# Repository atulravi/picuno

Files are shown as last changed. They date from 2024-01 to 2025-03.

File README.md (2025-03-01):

# PicUNO Series Of Boards By AtrivaTECH

AtrivaTECH Aims to bring the latest and greatest processors, chipsets and microcontrollers in the Custom PicUNO form factor derived from the Arduino UNO Form Factor. 

The PicUNO Line-Up of Open Source boards is as follows:
## Boards
1) RP2040 - https://github.com/atulravi/picuno/tree/main/RP2040
## Shields 
1) Lattice ICE50UP5K FPGA Shield - https://github.com/atulravi/picuno-ice
<br>
Current Version Under Test: V3.0.0 (RP2040)

## Information:

As development is consistent, documenting it, is not. To combat the same, various repositories and their purposes are given below. You may Follow the ones of choice to be notified when latest versions/updates are pushed.
1) Circuit Python port: https://github.com/atulravi/circuitpython
2) MicroPython Port: https://github.com/AtrivaTECH/micropython/tree/master
3) Arduino IDE Library: https://github.com/AtrivaTECH/AtrivaTECH_PicUNO
4) Documentation: https://github.com/AtrivaTECH/picuno-documentation
5) Project Repository: https://github.com/AtrivaTECH/picuno-projects
6) FPGA Shield: https://github.com/AtrivaTECH/picuno-ice

## Honorable Certifications:
v1-oshwa

## In The Press
687474703a2f2f6573636372617363692e696e2f77702d636f6e74656e742f75706c6f6164732f323032342f30342f4861636b737465725f5247422e6a7067
Hackster.io- "Atul Ravi's PicUNO is a Pico-style RP2040 board in the popular Arduino form factor with extra features."

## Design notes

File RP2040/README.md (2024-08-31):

# Picuno (PICO + UNO)
A repo of all files for the pic uno RP2040+Arduino UNO derivative by ESCcrasci and AtrivaTECH <br>

<i>Product Page:</i> <a href= "https://atrivatech.com/picuno">www.atrivatech.com/picuno</a><br>
<i>Brand Page/Manufacturer Page (All product updates in future will be available here):</i> <a href="https://www.atrivatech.com">www.atrivatech.com</a><br>
<i>Associated article:</i> https://esccrasci.in/picuno/ <br>

File Hierarchy will be updated periodically.<br>

<b><h3> CONTRIBUTORS, TESTERS are WELCOME. Know More: <a href="https://atrivatech.com/news">atrivatech.com/news</a></h3></b>

GPIOs <s>will be</s> are 5V tolerant (Select GPIOs) with level shifting. At the moment, <s>-6-</s> <b>4 </b> GPIOs will be level shifted to 5 volts unlike competitors. <s> Also working on shifting all GPIOs to 5V for better compatibility.</s> This shall work only with external power for safety reasons. (Note: Although GPIOS 2-5 are "OUTPUT ONLY" even inputs can be given. However, 5V inputs can only be given with external power. 3.3V inputs can be given with/without. Said GPIOs are maked as such to prevent accidents in hands of beginners. Said outputs will also be held HIGH always. For functionality, set low. These points are also applicable to 5V edition only.) Dual regulators are added for complete freedom of choosing devices to connect. (NOTE 2: Although both external power and USB power can be given at once, it is not recommended. However, the circuit has been designed to prevent reversing of high voltage through the USB. If considering external power and USB C, using a C cable without 5V line would be recommended.)<br> 

Built-In LED can be accessed at GPIO14.

SparkFun QWIIC/ Adafruit Stemma is also <s>going to be</s> implemented.  

Learning Resources shall be developed in partnership with the Educational Kits division of It's ON Group (AtrivaQ atrivaq.in) also providing a public platform for all users of PicUNO to share their learnings. Documentation and Learning Resources with Teaching Resources shall be produced in conjunction with our education team too. AtrivQ brings their over 4 year experience in the affordable education space which in conjunction with our affordable MCU board will gear up up-coming students,hobbyists and engineers to learn with the latest hardware without having to invest in sub-par foreign made knockoff boards.

Note that all of the gerber files and kicad files present at root are of V1 and can be ignored. File hierarchy shall be updated below soon. 
<br>
Cost Calculations and Expected Campaign goal can be found at <a href="https://github.com/atulravi/picuno/tree/main/RP2040/manufacture">/manufacture</a><br>
 
<b><i>Current version being <s>prototyped</s> tested:</i></b> V3.0.0 (Picuno RP2040)<br>

<hr width = 100% height = 2></hr>

# Information:
As development is consistent, documenting it, is not. To combat the same, various repositories and their purposes are given below. You may Follow the ones of choice to be notified when latest versions/updates are pushed.
1) Circuit Python port: https://github.com/atulravi/circuitpython
2) MicroPython Port: https://github.com/AtrivaTECH/micropython/tree/master
3) Arduino IDE Library: https://github.com/AtrivaTECH/AtrivaTECH_PicUNO
4) Documentation: https://github.com/AtrivaTECH/picuno-documentation
5) Project Repository: https://github.com/AtrivaTECH/picuno-projects
6) FPGA Shield: https://github.com/AtrivaTECH/picuno-ice

You may download software packages like uf2 files and latest library binaries from the "RELEASES" tab in each respective repository. 

# Software
As of now, custom editions of MicroPython and Circuitpython for our board have been made. However, until we obtain the PID codes, said versions will not be merged with the main repositories. However, the versions we have built will be available to test the board. 
Circuit Python: https://github.com/atulravi/circuitpython
MicroPython: https://github.com/AtrivaTECH/micropython/tree/master
Arduino IDE Library:  https://github.com/AtrivaTECH/AtrivaTECH_PicUNO

# Photo of PicUNO RP2040 V2.X.X


This particular version comes with 1 built-in LED, 1 WS2812 NeoPixel, Level SHifting to 5V on GPIOs 2-5 (On external power), Multi-GPIO support with selectors, SparkFun QWIIC/Adafruit Stemma QT connector, External DC Power jack, Dedicated reset switch, access to all 26 GPIOs and mounting holes. 
<hr width = 100% height = 2></hr>

## In the Press:


<small>The Hindu-Downtown-10 March</small>



<small>Hackster.io- "Atul Ravi's PicUNO is a Pico-style RP2040 board in the popular Arduino form factor with extra features."</small>

## Production Process

First Protoytpe (1)_page-0001
<small><center>Sections highlighted in green are complete</center></small>

## Known Faults: (GitHUB Issues can be used to track progress)
<s><19/APR> 3.3 and GND interchanged on headers. </s><br>
<1/APR> I2C and QWIIC wiring issue. GP20 is SDA and GP21 is SCL. Will Be fixed.

<h1><b>Licenses:</b></h1>

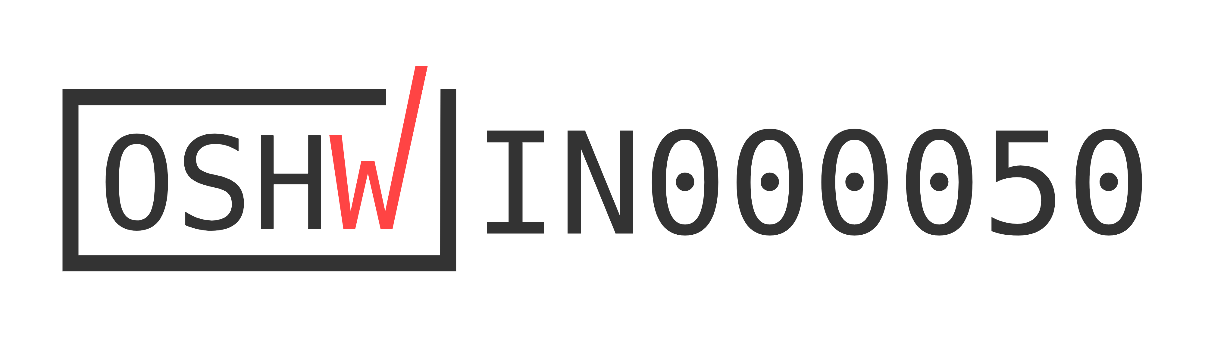
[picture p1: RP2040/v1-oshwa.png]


<hr width = 100% height = 2></hr>
<h1><b>Team:</b></h1>
<i>ATUL RAVI</i><br>
17 y/o hobbyist and student building hardware and blogging about them at https://www.esccrasci.in and HAM operator VU3FUJ <br>

## Credits
<small>Thanks to CodeItDoIt on Github for fixing the picuno.bmp filename and improving file hierarchy.</small>

<hr width = 100% height = 2></hr>


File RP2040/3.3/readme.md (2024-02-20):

3.3 Volt compatible version of the Picuno!
Comes with QWIIC, Built-In NeoPixel on GPIO14 and all other features except 5.5 Volt level shifting of the Picuno. Directly compatible with VGA and 3.3V Hats and shields.

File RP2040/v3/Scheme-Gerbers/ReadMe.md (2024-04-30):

Schematic and Gerber files for specific versions of PicUNO RP2040

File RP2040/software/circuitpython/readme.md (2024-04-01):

Contains all files related to CircuitPython for the Picuno

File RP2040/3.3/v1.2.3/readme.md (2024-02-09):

PICUNO 3.3V Version which is only 3.3 V compatible with all features as the 5V version.

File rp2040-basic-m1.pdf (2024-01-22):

rp2040-basic-m1
Id | Designator
1 | C12,C5
2 | SW2
3 | C6,C7,C3,C9,C11,C10,C4,C8
4 | U2
5 | J7
6 | R16,R6
7 | C14,C13
8 | R33,R3,R2
9 | 5V
10 | J6,J4
11 | R7
12 | C15

13 | J3
14 | D3
15 | R4,R5
16 | J5
17 | U1
18 | J1
19 | U3
20 | J9
21 | D2,D1
22 | J8
23 | C1,C2
24 | Y1

Footprint

C_0805_2012Metric_Pad1.18x1.45mm_HandSolder

SW_PUSH_6mm_H8.5mm

C_0603_1608Metric_Pad1.08x0.95mm_HandSolder

SOT-223-3_TabPin2

PinSocket_1x06_P2.54mm_Vertical

R_0805_2012Metric_Pad1.20x1.40mm_HandSolder

C_0805_2012Metric_Pad1.18x1.45mm_HandSolder

R_0805_2012Metric_Pad1.20x1.40mm_HandSolder

PinSocket_1x02_P2.54mm_Vertical

PinSocket_1x08_P2.54mm_Vertical

R_0805_2012Metric_Pad1.20x1.40mm_HandSolder

C_0805_2012Metric_Pad1.18x1.45mm_HandSolder

PinSocket_1x10_P2.54mm_Vertical

SOT-23

R_0603_1608Metric_Pad0.98x0.95mm_HandSolder

PinSocket_1x06_P2.54mm_Vertical

QFN-56-1EP_7x7mm_P0.4mm_EP3.2x3.2mm

USB_C_Receptacle_G-Switch_GT-USB-7010ASV

SOIC-8_5.23x5.23mm_P1.27mm

BarrelJack_Horizontal

D_0805_2012Metric_Pad1.15x1.40mm_HandSolder

PinSocket_1x03_P2.54mm_Vertical

C_0805_2012Metric_Pad1.18x1.45mm_HandSolder

Crystal_SMD_SeikoEpson_MA505-2Pin_12.7x5.1mm_Ha

Quantity | Designation | PLACED
2 | 1u | ☐
1 | TACT SW | ☐
8 | 100n | ☐
1 | AZ1117CH-3.3TRG1 SOT223-3 | ☐
1 | Conn_01x06_Socket | ☐
2 | 1k | ☐
2 | 10u | ☐
3 | 5.1K | ☐
1 | Conn_01x02_Pin | ☐
2 | Conn_01x08_Socket | ☐
1 | 10k | ☐
1 | 100n | ☐

Page

6

1 | Conn_01x10_Socket | ☐
1 | D_TVS_Dual_AAC | ☐
2 | 27R | ☐
1 | Conn_01x06_Pin | ☐
1 | RP2040 | ☐
1 | USB_C_Receptacle_USB2.0 | ☐
1 | W25Q128JVS | ☐
1 | Barrel_Jack_Switch | ☐
2 | D_Schottky | ☐
1 | Conn_01x03_Pin | ☐
2 | 27p | ☐
1 | Crystal 12 Mhz | ☐

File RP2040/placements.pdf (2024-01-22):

Id | Designator | Footprint | Quantity | Designation | PLACED
1 | C12,C5 | C_0805_2012Metric_Pad1.18x1.45mm_HandSolder | 2 | 1u
2 | SW2 | SW_PUSH_6mm_H8.5mm | 1 | TACT SW
3 | C6,C7,C3,C9,C11,C10,C4,C8 | C_0603_1608Metric_Pad1.08x0.95mm_HandSolder | 8 | 100n
4 | U2 | SOT-223-3_TabPin2 | 1 | AZ1117CH-3.3TRG1 SOT223-3
5 | J7 | PinSocket_1x06_P2.54mm_Vertical | 1 | Conn_01x06_Socket
6 | R16,R6 | R_0805_2012Metric_Pad1.20x1.40mm_HandSolder | 2 | 1k
7 | C14,C13 | C_0805_2012Metric_Pad1.18x1.45mm_HandSolder | 2 | 10u
8 | R33,R3,R2 | R_0805_2012Metric_Pad1.20x1.40mm_HandSolder | 3 | 5.1K
9 | 5V | PinSocket_1x02_P2.54mm_Vertical | 1 | Conn_01x02_Pin
10 | J6,J4 | PinSocket_1x08_P2.54mm_Vertical | 2 | Conn_01x08_Socket
11 | R7 | R_0805_2012Metric_Pad1.20x1.40mm_HandSolder | 1 | 10k
12 | C15 | C_0805_2012Metric_Pad1.18x1.45mm_HandSolder | 1 | 100n
13 | J3 | PinSocket_1x10_P2.54mm_Vertical | 1 | Conn_01x10_Socket
14 | D3 | SOT-23 | 1 | D_TVS_Dual_AAC
15 | R4,R5 | R_0603_1608Metric_Pad0.98x0.95mm_HandSolder | 2 | 27R

16 | J5 | PinSocket_1x06_P2.54mm_Vertical | 1 | Conn_01x06_Pin
17 | U1 | QFN-56-1EP_7x7mm_P0.4mm_EP3.2x3.2mm | 1 | RP2040
18 | J1 | USB_C_Receptacle_G-Switch_GT-USB-7010ASV | 1 | USB_C_Receptacle_USB2.0
19 | U3 | SOIC-8_5.23x5.23mm_P1.27mm | 1 | W25Q128JVS
20 | J9 | BarrelJack_Horizontal | 1 | Barrel_Jack_Switch
21 | D2,D1 | D_0805_2012Metric_Pad1.15x1.40mm_HandSolder | 2 | D_Schottky
22 | J8 | PinSocket_1x03_P2.54mm_Vertical | 1 | Conn_01x03_Pin
23 | C1,C2 | C_0805_2012Metric_Pad1.18x1.45mm_HandSolder | 2 | 27p
24 | Y1 | Crystal_SMD_SeikoEpson_MA505-2Pin_12.7x5.1mm_HandSoldering 1 | | Crystal 12 Mhz

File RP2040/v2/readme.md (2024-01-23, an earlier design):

Files of V2 including KiCad files added. Will be updated periodically when chanes are made. V2 also has 2 additional LEDs and minor issues in V1 fixed in V2!

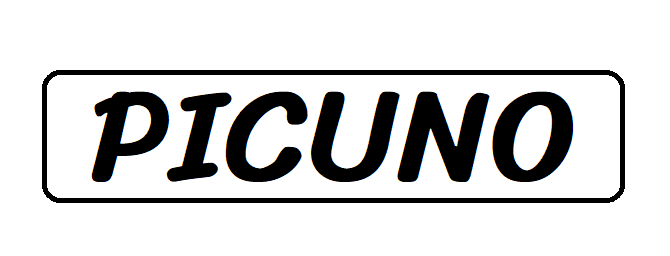
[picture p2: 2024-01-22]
RP2040/picuno.bmp

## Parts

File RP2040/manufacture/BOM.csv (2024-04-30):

 |  |  |  |  |  | 5*5*5 |  |  |  | 10*10*10 |  |  |  | 5*5*2
Id | Designator | Footprint | Quantity | Designation | SKU | Board Qty | Part Qty | Per Piece | Amnt | Board Qty2 | Part Qty3 | Per Piece4 | Amnt5 | Board Qty2 | Part Qty3 | Per Piece4 | Amnt5
1 | SW2 | SW_SPST_TL3342 | 1 | 4*4*1/5 SMD tact SW | KSTS0760 | 125 | 125 | 1.08 | 135 | 500 | 500 | 1.08 | 540 | 50 | 50 | 1.08 | 54
2 | C6,C7,C15,C3,C9,C11,C10,C4,C8 | C_0603_1608Metric_Pad1.08x0.95mm_HandSolder | 9 | 100n | KSTC1342 | 125 | 1125 | 0.64 | 720 | 500 | 4500 | 0.64 | 2880 | 50 | 450 | 0.64 | 288
3 | U2 | SOT-223-3_TabPin2 | 1 | AZ1117CH-3.3TRG1 SOT223-3 | KSTI0045 | 125 | 125 | 4.23 | 528.75 | 500 | 500 | 4.23 | 2115 | 50 | 50 | 4.23 | 211.5
4 | J7 | PinSocket_1x06_P2.54mm_Vertical | 1 | Conn_01x06_Socket | ST2106CO4027 | 125 | 125 | 6.26 | 782.5 | 500 | 500 | 6.26 | 3130 | 50 | 50 | 6.26 | 313
5 | J5 | PinSocket_1x06_P2.54mm_Vertical | 1 | Conn_01x06_Pin | ST2106CO4027 | 125 | 125 | 6.26 | 782.5 | 500 | 500 | 6.26 | 3130 | 50 | 50 | 6.26 | 313
6 | R20,R21,R14,R13,R11,R22,R12,R23 | R_0603_1608Metric_Pad0.98x0.95mm_HandSolder | 8 | 10K | KSTR0853 | 125 | 1000 | 0.18 | 180 | 500 | 4000 | 0.18 | 720 | 50 | 400 | 0.18 | 72
7 | R8,R1 | R_0603_1608Metric_Pad0.98x0.95mm_HandSolder | 2 | 220 | KSTR1359 | 125 | 250 | 0.22 | 55 | 500 | 1000 | 0.22 | 220 | 50 | 100 | 0.22 | 22
8 | J6,J4 | PinSocket_1x08_P2.54mm_Vertical | 2 | Conn_01x08_Socket | ST2106CO4029 | 125 | 250 | 7.79 | 1947.5 | 500 | 1000 | 7.79 | 7790 | 50 | 100 | 7.79 | 779
9 | JP3 | SolderJumper-3_P1.3mm_Open_Pad1.0x1.5mm | 1 | Jumper_3_Open |  | 125 | 125 |  |  | 500 | 500 |  |  | 50 | 50
10 | Q5,Q4,Q3,Q6 | SOT-23 | 4 | BSS138 | KSTM0717 | 125 | 500 | 1.21 | 605 | 500 | 2000 | 1.21 | 2420 | 50 | 200 | 1.21 | 242
11 | C5,C12 | C_0603_1608Metric_Pad1.08x0.95mm_HandSolder | 2 | 1u | KSTC0823 | 125 | 250 | 0.65 | 162.5 | 500 | 1000 | 0.65 | 650 | 50 | 100 | 0.65 | 65
12 | R16,R6 | R_0603_1608Metric_Pad0.98x0.95mm_HandSolder | 2 | 1k | KSTR0854 | 125 | 250 | 0.22 | 55 | 500 | 1000 | 0.22 | 220 | 50 | 100 | 0.22 | 22
13 | J3 | PinSocket_1x10_P2.54mm_Vertical | 1 | Conn_01x10_Socket | ST2106CO4031 | 125 | 125 | 6.83 | 853.75 | 500 | 500 | 6.83 | 3415 | 50 | 50 | 6.83 | 341.5
14 | C1,C2 | C_0603_1608Metric_Pad1.08x0.95mm_HandSolder | 2 | 27p | 059-0603N270J500CT | 125 | 250 | 0.92 | 230 | 500 | 1000 | 0.92 | 920 | 50 | 100 | 0.92 | 92
15 | D3 | SOT-23 | 1 | D_TVS_Dual_AAC | KSTD0106 | 125 | 125 | 6.36 | 795 | 500 | 500 | 6.36 | 3180 | 50 | 50 | 6.36 | 318
16 | Y1 | Crystal_SMD_3225-4Pin_3.2x2.5mm | 1 | \YSX321SL 12 Mhz | KSTC1119 | 125 | 125 | 11 | 1375 | 500 | 500 | 11 | 5500 | 50 | 50 | 11 | 550
17 | JP4 | SolderJumper-2_P1.3mm_Open_RoundedPad1.0x1.5mm | 1 | Jumper_2_Open |  | 125 | 125 |  |  | 500 | 500 |  |  | 50 | 50
18 | F1 | Fuse_1206_3216Metric_Pad1.42x1.75mm_HandSolder | 1 | Fuse | KSTF0733 | 125 | 125 | 4.67 | 583.75 | 500 | 500 | 4.67 | 2335 | 50 | 50 | 4.67 | 233.5
19 | U4 | SOT-223-3_TabPin2 | 1 | AMS1117-5.0 | KSTI0851 | 125 | 125 | 4.9 | 612.5 | 500 | 500 | 4.9 | 2450 | 50 | 50 | 4.9 | 245
20 | R4,R5 | R_0603_1608Metric_Pad0.98x0.95mm_HandSolder | 2 | 27R | 058-0603SAJ07270T5E | 125 | 250 | 0.56 | 140 | 500 | 1000 | 0.56 | 560 | 50 | 100 | 0.56 | 56
21 | JP2,JP1 | SolderJumper-2_P1.3mm_Open_RoundedPad1.0x1.5mm | 2 | Jumper_2_Bridged |  | 125 | 250 |  |  | 500 | 1000 |  |  | 50 | 100
22 | J2 | JST_SM04B-SRSS-TB_LF__SN_ | 1 | SM04B-SRSS-TB_LF__SN_ | 083-EQ-SM04B-SRSS-TB-W | 125 | 125 | 12 | 1500 | 500 | 500 | 12 | 6000 | 50 | 50 | 12 | 600
23 | C14,C13 | C_0603_1608Metric_Pad1.08x0.95mm_HandSolder | 2 | 10u | KSTC0826 | 125 | 250 | 3.39 | 847.5 | 500 | 1000 | 3.39 | 3390 | 50 | 100 | 3.39 | 339
24 | D5,D4 | LED_0805_2012Metric_Pad1.15x1.40mm_HandSolder | 2 | LED | KSTL0464 | 125 | 250 | 0.57 | 142.5 | 500 | 1000 | 0.57 | 570 | 50 | 100 | 0.57 | 57
25 | R2,R33,R3 | R_0603_1608Metric_Pad0.98x0.95mm_HandSolder | 3 | 5.1K | KSTR1150 | 125 | 375 | 0.22 | 82.5 | 500 | 1500 | 0.22 | 330 | 50 | 150 | 0.22 | 33
26 | J10 | PinHeader_1x02_P2.54mm_Vertical | 1 | Conn_01x02_Pin |  | 125 | 125 |  |  | 500 | 500 |  |  | 50 | 50
27 | U1 | QFN-56-1EP_7x7mm_P0.4mm_EP3.2x3.2mm | 1 | RP2040 | KSTI1038 | 125 | 125 | 65.17 | 8146.25 | 500 | 500 | 65.17 | 32585 | 50 | 50 | 65.17 | 3258.5
28 | J1 | USB_C_Receptacle_G-Switch_GT-USB-7010ASV | 1 | USB_C_Receptacle_USB2.0 | KSTC0844 | 125 | 125 | 4.44 | 555 | 500 | 500 | 4.44 | 2220 | 50 | 50 | 4.44 | 222
29 | U3 | SOIC-8_5.23x5.23mm_P1.27mm | 1 | W25Q128JVS | KSTI0450 | 125 | 125 | 28.93 | 3616.25 | 500 | 500 | 28.93 | 14465 | 50 | 50 | 28.93 | 1446.5
30 | SW1 | SW_SPST_TL3342 | 1 | TACT SW | KSTS0760 | 125 | 125 | 1.08 | 135 | 500 | 500 | 1.08 | 540 | 50 | 50 | 1.08 | 54
31 | D2 | LED_WS2812B_PLCC4_5.0x5.0mm_P3.2mm | 1 | WS2812B | KSTL0917 | 125 | 125 | 3.69 | 461.25 | 500 | 500 | 3.69 | 1845 | 50 | 50 | 3.69 | 184.5
32 | J9 | BarrelJack_Horizontal | 1 | Barrel_Jack_Switch | KSTC0508 | 125 | 125 | 3.9 | 487.5 | 500 | 500 | 3.9 | 1950 | 50 | 50 | 3.9 | 195
33 | J8 | PinSocket_1x03_P2.54mm_Vertical | 1 | Conn_01x03_Pin |  | 125 | 125 |  |  | 500 | 500 |  |  | 50 | 50
34 | R15,R17 | R_0603_1608Metric_Pad0.98x0.95mm_HandSolder | 2 | 2.2K | 058-0603WAF2201T5E | 125 | 250 | 0.36 | 90 | 500 | 1000 | 0.36 | 360 | 50 | 100 | 0.36 | 36
35 | R7 | R_0603_1608Metric_Pad0.98x0.95mm_HandSolder | 1 | 10k | KSTR0853 | 125 | 125 | 0.22 | 27.5 | 500 | 500 | 0.22 | 110 | 50 | 50 | 0.22 | 11
36 | D1 | D_SOD-128 | 1 | D_Schottky | KSTD0107 | 125 | 125 | 1.47 | 183.75 | 500 | 500 | 1.47 | 735 | 50 | 50 | 1.47 | 73.5
 |  |  |  |  | NET COST |  |  |  | 26818.75 |  |  |  | 107275 |  |  |  | 10727.5

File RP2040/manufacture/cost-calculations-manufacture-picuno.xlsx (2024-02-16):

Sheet: Lion
Sno | Item | Cost | QTY | Amount
1 | Components | 160 | 50
2 | PCB | 100.83 | 50
3 | Assembly | 279.73 | 50
4 | Box | 20.5 | 50
5 | ESD Cover | 32.5 | 50
6 | A3 manual | 10 | 50
 | Net Cost | 603.56 | 300 | 0
 | Expected Cost | 767.75
 | Profit %

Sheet: PCB-Power
 |  | 5*5*5 |  |  | 10*10*5 |  |  | 20*10*5 |  |  | 5*5*2
Sno | Item | Cost/piece | QTY | Amount | QTY | Amount | cost/piece | QTY | Amount | cost/piece | QTY | Amount | cost/piece
1 | Components | 214.55 | 125 | 26818.75 | 500 | 107275 | 214.55 | 1000 | 214550 | 214.55 | 50 | 10727.5 | 214.55
2 | PCB | 72.64 | 125 | 9080 | 500 | 19842 | 39.684 | 1000 | 30373 | 30.373 | 50 | 4210 | 84.2
3 | Assembly | 276.216 | 125 | 34527 | 500 | 118000 | 236 | 1000 | 210229 | 210.229 | 50 | 16159 | 323.18
4 | Box | 20.5 | 125 | 2562.5 | 500 | 10250 | 20.5 | 1000 | 20500 | 20.5 | 50 | 1025 | 20.5
5 | ESD Cover | 32.5 | 125 | 4062.5 | 500 | 16250 | 32.5 | 1000 | 32500 | 32.5 | 50 | 1625 | 32.5
6 | A3 manual | 10 | 125 | 1250 | 500 | 5000 | 10 | 1000 | 10000 | 10 | 50 | 500 | 10
 | Net Cost | 626.406 |  | 78300.75 |  | 276617 | 553.234 |  | 518152 | 518.152 |  | 34246.5 | 684.93
 | Expected Cost | 730.4 |  |  |  |  | 730.4 |  |  | 730.4 |  |  | 730.4
 | Profit % | 16.60169283 |  |  |  |  | 32.02370064 |  |  | 40.96249749 |  |  | 6.638634605
 | USD $ |  |  | 943.3825301 |  | 3332.73494 |  |  | 6242.795181 |  |  | 412.6084337
 | Labour |  |  | 103.994 |  |  | 177.166 |  |  | 212.248 |  |  | 45.47
 |  | 1999.813693

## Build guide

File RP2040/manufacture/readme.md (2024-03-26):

BOM (Part pricing), Final Manufacture estimate.   Subject to change. 
<br>
If product will ever be crowd-funded, cost of each piece expected at ~8-10 USD a piece. 

<b>Expected campaign Goal: $2800-$3900 </b>
<br>
Possible Fab of choice: Lion Circuits (Bangalore-India)

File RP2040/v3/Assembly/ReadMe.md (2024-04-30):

Files for easy assembly of PicUNO. Limited to specific versions.

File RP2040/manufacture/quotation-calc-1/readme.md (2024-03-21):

Calculated costs based on quotations received from 2 fabs. PCBPower and LionCircuits. India. 

<b>Date of upload: <i>22/Mar/23</i></b>

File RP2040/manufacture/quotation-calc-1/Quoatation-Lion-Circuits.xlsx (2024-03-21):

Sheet: Max Lead Time
COST FOR QUANTITY QUOTE
QTY | 20 | 50 | 100 | 200 | 250 | 500
PCB | 4676 | 6606 | 8950 | 12566 | 14068 | 20988
ASSEMBLY | 3000 | 6250 | 9300 | 15600 | 19500 | 25500
Total | 7676 | 12856 | 18250 | 28166 | 33568 | 46488
For Lion Circuits. Please fill appropriate column with cost for maximum lead time.
One time stencil cost
 | Framed | Rs 8000/- + GST
 | Frameless | Rs 4000/- + GST
Assembly NRE | Rs 2000/- + GST

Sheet: Fastest Lead Time
COST FOR QUANTITY QUOTE
QTY | 20 | 50 | 100 | 200 | 250 | 500
PCB | 5015 | 7051 | Not supported under Rush Service
ASSEMBLY | 3000 | 6250 | 9300 | 15600 | 19500 | 25500
Total
For Lion Circuits.Please fill appropriate column with cost for least lead time
One time stencil cost
 | Framed | Rs 8000/- + GST
 | Frameless | Rs 4000/- + GST
Assembly NRE | Rs 2000/- + GST

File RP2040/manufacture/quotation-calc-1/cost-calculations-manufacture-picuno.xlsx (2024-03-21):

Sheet: Lion
 |  | 50 |  |  | 100 |  |  | 200 |  |  | 250 |  |  | 500
Sno | Item | Cost/piece | QTY | Amount | QTY | Amount | cost/piece | QTY | Amount | cost/piece | QTY | Amount | cost/piece | QTY | Amount | cost/piece
1 | Components | 218.118 | 50 | 10905.9 | 100 | 21425.8 | 214.258 | 200 | 42309.6 | 211.548 | 250 | 52277 | 209.108 | 500 | 101965 | 203.93
2 | PCB | 132.12 | 50 | 6606 | 100 | 8950 | 89.5 | 200 | 12566 | 62.83 | 250 | 14068 | 56.272 | 500 | 20988 | 41.976
3 | Assembly | 125 | 50 | 6250 | 100 | 9300 | 93 | 200 | 15600 | 78 | 250 | 19500 | 78 | 500 | 25500 | 51
4 | Box | 20.5 | 50 | 1025 | 100 | 2050 | 20.5 | 200 | 4100 | 20.5 | 250 | 5125 | 20.5 | 500 | 10250 | 20.5
5 | ESD Cover | 32.5 | 50 | 1625 | 100 | 3250 | 32.5 | 200 | 6500 | 32.5 | 250 | 8125 | 32.5 | 500 | 16250 | 32.5
6 | A3 manual | 10 | 50 | 500 | 100 | 1000 | 10 | 200 | 2000 | 10 | 250 | 2500 | 10 | 500 | 5000 | 10
7 | Stencil | 1 | 4000 | 4000 | 4000 | 4000 | 1 | 4000 | 4000 | 1 | 4000 | 4000 | 1 | 4000 | 4000 | 1
8 | NRE | 1 | 2000 | 2000 | 2000 | 2000 | 1 | 2000 | 2000 | 1 | 2000 | 2000 | 1 | 2000 | 2000 | 1
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

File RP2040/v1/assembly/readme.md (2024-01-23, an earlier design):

Files to assemble one's own picuno V1 including BOM, Assembly Checklist uploaded

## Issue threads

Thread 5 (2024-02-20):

Typo in readme of manufacture

CodeItDoIt, 2024-02-20:
BOM coshting which I presume is costing.

atulravi, 2024-02-20:
Fixed.

Closed 2024-02-20.

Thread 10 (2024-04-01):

SCL SDA mixup and Mounting Hole misplacement to be fixed.

atulravi, 2024-04-01:
It is to be noted that in 2.2.3 GP20 is SDA and GP21 is SCL. Not vice versa. Issue to be fixed ASAP

atulravi, 2024-04-30:
Fixed in RP2040 V3

Closed 2024-04-30.

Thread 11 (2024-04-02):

Level Shifted GPIOS stay High always

atulravi, 2024-04-02:
Possible software fix is required for the same.

atulravi, 2024-04-11:
Fixed in custom libraries for MicroPython and CPY and arduino IDE.

Closed 2024-04-11.

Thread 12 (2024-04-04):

Library with examples and features for Ard IDE

atulravi, 2024-04-04:
As the title says. Library o be made with example code for each testing capability. Also possibly fixing LED builtin function too.

atulravi, 2024-04-17:
Done!!! More examples to be added. Opened as issue in library github.

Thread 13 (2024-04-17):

Compatibility issue found with Multifunction Shield

atulravi, 2024-04-17:
As found by onecircuit-as, Shield seems to be shorting something. Not sure what yet. Shield bought for testing.

atulravi, 2024-04-19:
Issue seems to be because IOREF after reset is going to ground. This is because it is 5V on Uno. But ground on PicUNO. 3.3 and GND to be interchanged.

Closed 2024-04-19.

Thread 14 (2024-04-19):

Interchange first 3.3 and Gnd with eachother

atulravi, 2024-04-19:
Fundamental flaw on PicUNO. On UNO, first pin on Power headers is GND. Second is 5V. On PicUNO it is vice-versa. TO be fixed.

atulravi, 2024-04-20:
Issue fixed in latest release. Refer to release docs for further details: https://github.com/atulravi/picuno/releases/tag/V2.5.0

Closed 2024-04-20.

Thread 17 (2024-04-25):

New Version to be made

atulravi, 2024-04-25:
New version currently being designed. Suggested changes:
1) Updated osc design
2) Better regulators
3) Mosfet for external Power and USB C differentiation (Based on WizCube by Vasillis Vorrias (PicUNO Tester))
4) Mounting Hole Placement
5) Changing SCL SDA text in back
6) Changing all 0603 to 0402 part sizes.
7) Relocating LED Builtin and Power LED

Global Changes to be made:
Documentation and Sample Projects.

atulravi, 2024-04-30:
MOSFET replaced with Switch for safety.

atulravi, 2024-05-13:
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
Done 👍

Closed 2024-05-13.

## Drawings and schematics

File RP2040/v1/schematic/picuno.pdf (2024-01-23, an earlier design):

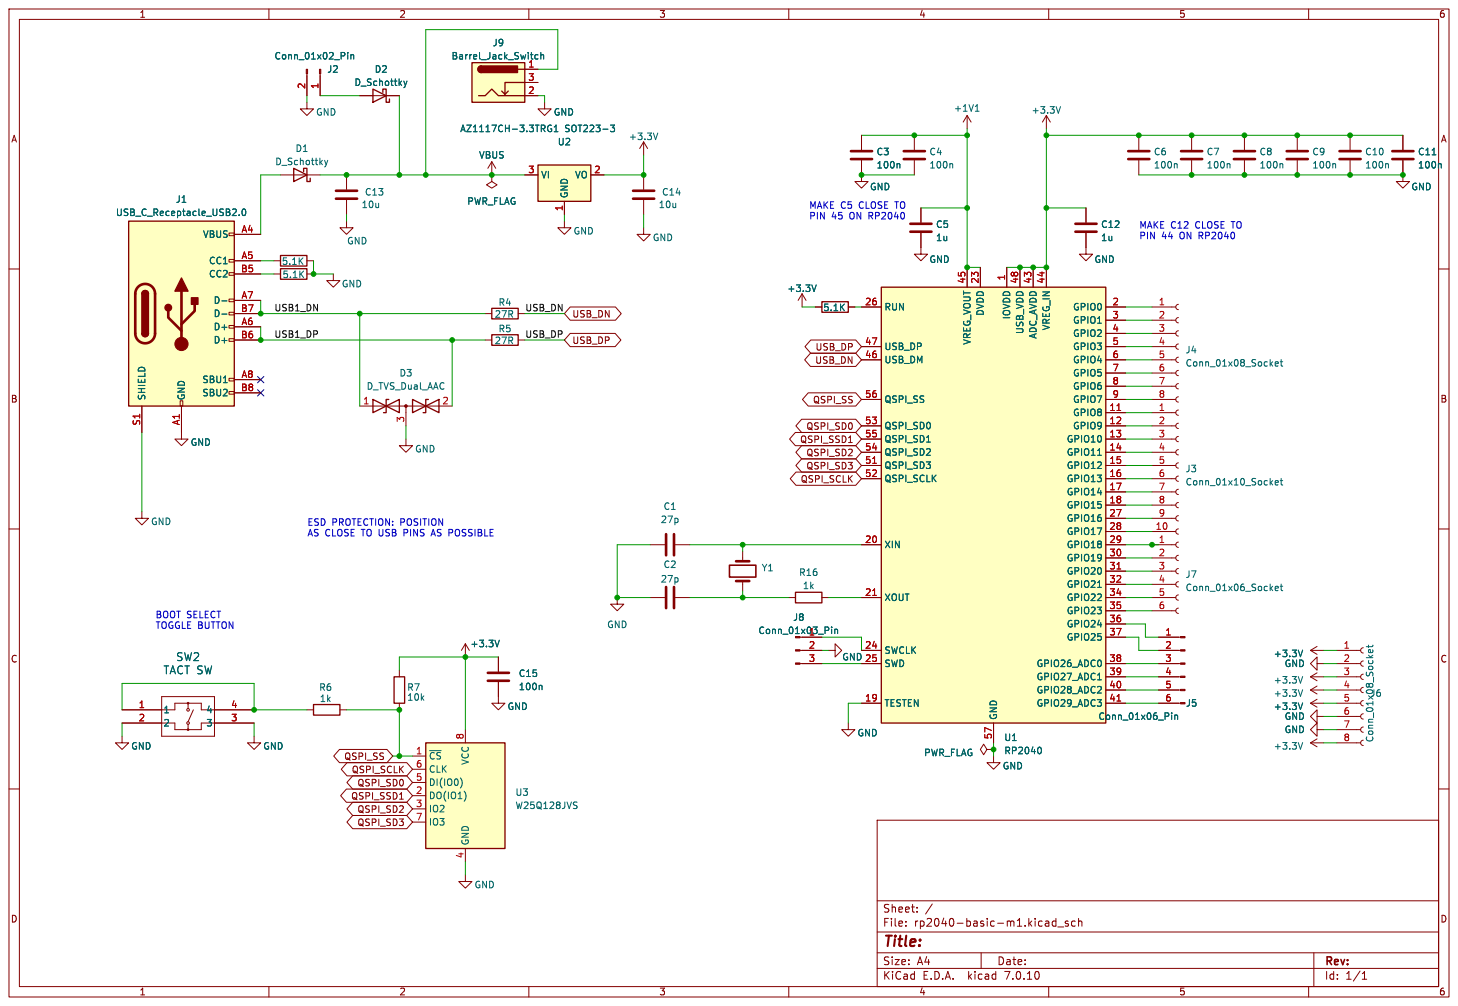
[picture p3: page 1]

PIN 45 ON RP2040 ESD PROTECTION: POSITION

PIN 44 ON RP2040 MAKE C5 CLOSE TO

1 GPIO8 11 GPIO9 12 GPIO10 13 GPIO11 14 GPIO12 15 GPIO13 16 GPIO14 17 GPIO15 18 TESTEN 19 GPIO0 2 XIN 20 XOUT 21 DVDD 23 SWCLK 24 SWD 25 RUN 26 GPIO16 27 GPIO17 28 GPIO18 29 GPIO1 3 GPIO19 30 GPIO20 31 GPIO21 32 GPIO22 34 GPIO23 35 GPIO24 36 GPIO25 37 GPIO26_ADC0 38 GPIO27_ADC1 39 GPIO2 4 GPIO28_ADC2 40 GPIO29_ADC3 41 ADC_AVDD 43 VREG_IN 44 VREG_VOUT 45 USB_DM 46 USB_DP 47 USB_VDD 48 GPIO3 5 QSPI_SD3 51 QSPI_SCLK 52 QSPI_SD0 53 QSPI_SD2 54 QSPI_SD1 55 QSPI_SS 56 GND 57 GPIO4 6 GPIO5 7 GPIO6 8 GPIO7 9 U1 PWR_FLAG RP2040

1 GPIO8 11 GPIO9 12 GPIO10 13 GPIO11 14 GPIO12 15 GPIO13 16 GPIO14 17 GPIO15 18 TESTEN 19 GPIO0 2 XIN 20 XOUT 21 DVDD 23 SWCLK 24 SWD 25 RUN 26 GPIO16 27 GPIO17 28 GPIO18 29 GPIO1 3 GPIO19 30 GPIO20 31 GPIO21 32 GPIO22 34 GPIO23 35 GPIO24 36 GPIO25 37 GPIO26_ADC0 38 GPIO27_ADC1 39 GPIO2 4 GPIO28_ADC2 40 GPIO29_ADC3 41 ADC_AVDD 43 VREG_IN 44 VREG_VOUT 45 USB_DM 46 USB_DP 47 USB_VDD 48 GPIO3 5 QSPI_SD3 51 QSPI_SCLK 52 QSPI_SD0 53 QSPI_SD2 54 QSPI_SD1 55 QSPI_SS 56 GND 57 GPIO4 6 GPIO5 7 GPIO6 8 GPIO7 9 GND

AS CLOSE TO USB PINS AS POSSIBLE

Id: 1/1 Title: File: rp2040-basic-m1.kicad_sch Sheet: /

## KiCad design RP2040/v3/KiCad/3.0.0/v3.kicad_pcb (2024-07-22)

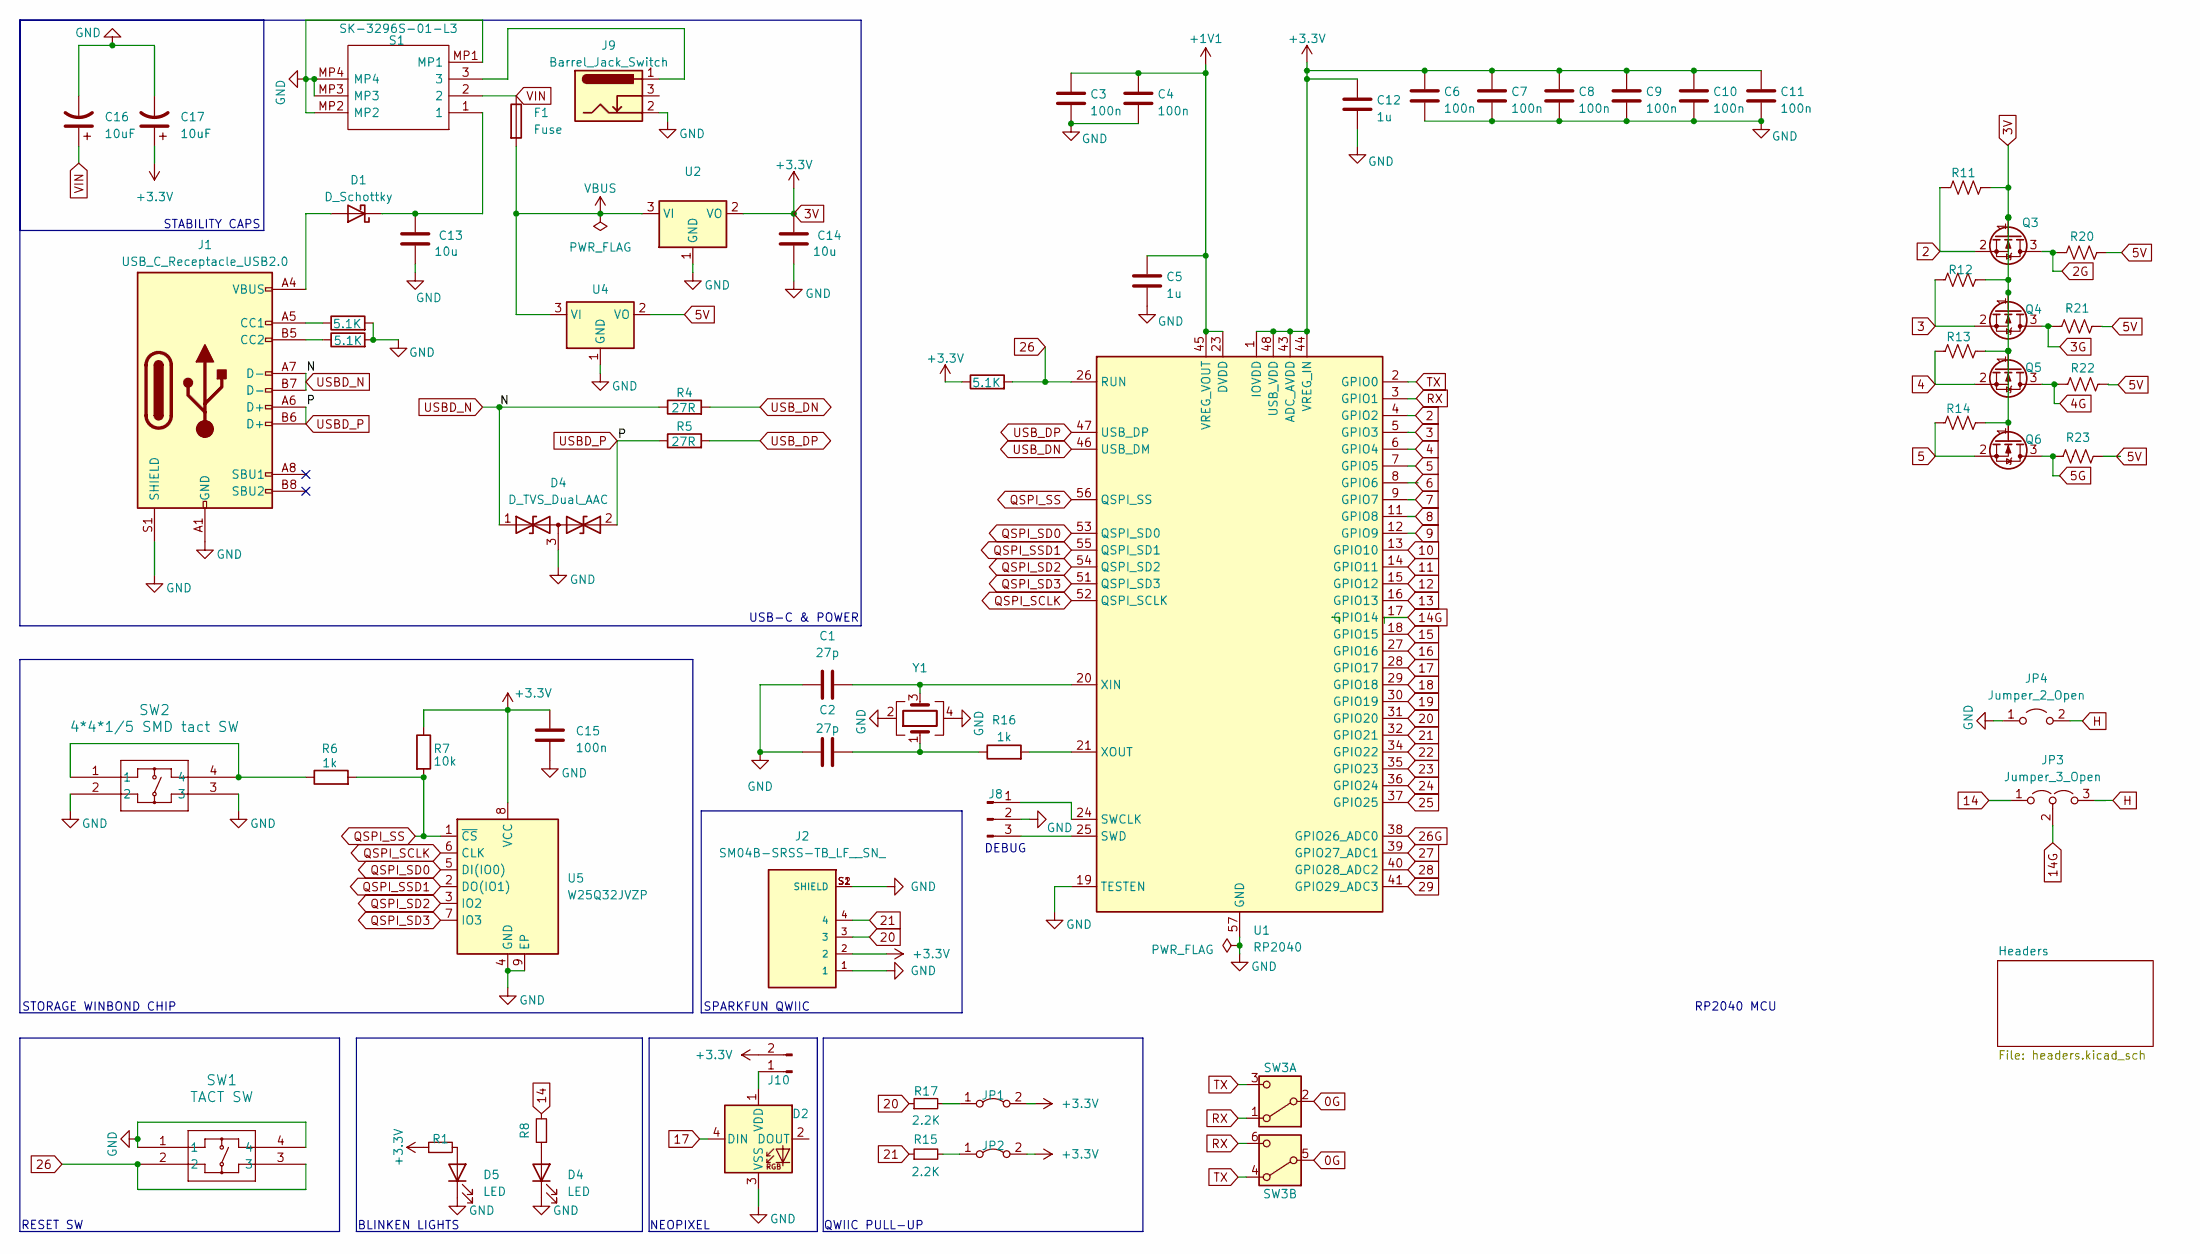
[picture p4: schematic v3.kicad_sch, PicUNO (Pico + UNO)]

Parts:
C1, C2: 27p; C_0402_1005Metric_Pad0.74x0.62mm_HandSolder
C3, C4, C6, C7, C8, C9, C10, C11, C15: 100n; C_0402_1005Metric_Pad0.74x0.62mm_HandSolder
C5, C12: 1u; C_0402_1005Metric_Pad0.74x0.62mm_HandSolder
C13, C14: 10u; C_0402_1005Metric_Pad0.74x0.62mm_HandSolder
C16, C17: 10uF; CP_Elec_4x5.4; LCSC C4747971
D1: D_Schottky; D_SOD-128
D2: WS2812B; LED_WS2812B_PLCC4_5.0x5.0mm_P3.2mm
D4: D_TVS_Dual_AAC; SOT-23
D5: LED; LED_0805_2012Metric_Pad1.15x1.40mm_HandSolder
F1: Fuse; Fuse_1206_3216Metric_Pad1.42x1.75mm_HandSolder
J1: USB_C_Receptacle_USB2.0; USB_C_Receptacle_G-Switch_GT-USB-7010ASV
J2: SM04B-SRSS-TB_LF__SN_; JST_SM04B-SRSS-TB_LF__SN_
J8: Conn_01x03_Pin; PinSocket_1x03_P2.54mm_Vertical
J9: Barrel_Jack_Switch; BarrelJack_Horizontal
J10: Conn_01x02_Pin; PinHeader_1x02_P2.54mm_Vertical
JP1, JP2: Jumper_2_Bridged; SolderJumper-2_P1.3mm_Open_RoundedPad1.0x1.5mm
JP3: Jumper_3_Open; SolderJumper-3_P1.3mm_Open_Pad1.0x1.5mm
JP4: Jumper_2_Open; SolderJumper-2_P1.3mm_Open_RoundedPad1.0x1.5mm
Q3, Q4, Q5, Q6: BSS138; SOT-23
R1, R8: 220; R_0402_1005Metric_Pad0.72x0.64mm_HandSolder
R2, R3, R33: 5.1K; R_0402_1005Metric_Pad0.72x0.64mm_HandSolder
R4, R5: 27R; R_0402_1005Metric_Pad0.72x0.64mm_HandSolder
R6, R16: 1k; R_0402_1005Metric_Pad0.72x0.64mm_HandSolder
R7: 10k; R_0402_1005Metric_Pad0.72x0.64mm_HandSolder
R11, R12, R13, R14, R20, R21, R22, R23: 10K; R_0402_1005Metric_Pad0.72x0.64mm_HandSolder
R15, R17: 2.2K; R_0402_1005Metric_Pad0.72x0.64mm_HandSolder
S1: SK-3296S-01-L3; SK3296S01L3; Manufacturer_Part_Number SK-3296S-01-L3
SW1: TACT SW; SW_SPST_TL3342
SW2: 4*4*1/5 SMD tact SW; SW_SPST_TL3342
SW3: SW_DPDT_x2; SW_CL-SB-22A-02T; MFG Part No C2904912
U1: RP2040; QFN-56-1EP_7x7mm_P0.4mm_EP3.2x3.2mm
U2: AZ1117CH-3.3TRG1 SOT223-3; SOT-223-3_TabPin2
U4: AMS1117-5.0; SOT-223-3_TabPin2
U5: W25Q32JVZP; WSON-8-1EP_6x5mm_P1.27mm_EP3.4x4.3mm
Y1: \YSX321SL 12 Mhz; Crystal_SMD_3225-4Pin_3.2x2.5mm

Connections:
0G: SW3.2 (B), SW3.5 (B)
2: Q3.2 (S), R11.1, U1.4 (GPIO2)
2G: Q3.3 (D), R20.1
3: Q4.2 (S), R12.1, U1.5 (GPIO3)
3G: Q4.3 (D), R21.1
3V: C6.1, C7.1, C8.1, C9.1, C10.1, C11.1, C12.1, C14.1, C15.1, C17.1, J2.2, J10.2, JP1.2 (B), JP2.2 (B), Q3.1 (G), Q4.1 (G), Q5.1 (G), Q6.1 (G), R1.1, R7.1, R11.2, R12.2, R13.2, R14.2, R33.1, U1.1 (IOVDD), U1.10 (IOVDD), U1.22 (IOVDD), U1.33 (IOVDD), U1.42 (IOVDD), U1.43 (ADC_AVDD), U1.44 (VREG_IN), U1.48 (USB_VDD), U1.49 (IOVDD), U2.2 (VO), U5.8 (VCC); also elsewhere on the board
4: Q5.2 (S), R13.1, U1.6 (GPIO4)
4G: Q5.3 (D), R22.1
5: Q6.2 (S), R14.1, U1.7 (GPIO5)
5G: Q6.3 (D), R23.1
5V: R20.2, R21.2, R22.2, R23.2, U4.2 (VO); also elsewhere on the board
6: U1.8 (GPIO6)
7: U1.9 (GPIO7)
8: U1.11 (GPIO8)
9: U1.12 (GPIO9)
10: U1.13 (GPIO10)
11: U1.14 (GPIO11)
12: U1.15 (GPIO12)
13: U1.16 (GPIO13)
14: JP3.1 (A), R8.2
14G: JP3.2 (C), U1.17 (GPIO14)
15: U1.18 (GPIO15)
16: U1.27 (GPIO16)
17: D2.4 (DIN), U1.28 (GPIO17); also elsewhere on the board
18: U1.29 (GPIO18)
19: U1.30 (GPIO19)
20: J2.3, R17.1, U1.31 (GPIO20); also elsewhere on the board
21: J2.4, R15.1, U1.32 (GPIO21); also elsewhere on the board
22: U1.34 (GPIO22)
23: U1.35 (GPIO23)
24: U1.36 (GPIO24); also elsewhere on the board
25: U1.37 (GPIO25); also elsewhere on the board
26: R33.2, SW1.2, SW1.3, U1.26 (RUN); also elsewhere on the board
26G: U1.38 (GPIO26_ADC0)
27: U1.39 (GPIO27_ADC1)
28: U1.40 (GPIO28_ADC2)
29: U1.41 (GPIO29_ADC3)
+1V1: C3.1, C4.1, C5.1, U1.23 (DVDD), U1.45 (VREG_VOUT), U1.50 (DVDD)
H: JP3.3 (B), JP4.2 (B)
unnamed: C2.2, R16.1, Y1.1
unnamed: D1.2 (A), J1.A4 (VBUS), J1.A9 (VBUS), J1.B4 (VBUS), J1.B9 (VBUS)
unnamed: C13.1, D1.1 (K), S1.1
unnamed: D2.1 (VDD), J10.1
unnamed: D5.2 (A), R1.2
unnamed: J1.A5 (CC1), R2.1
unnamed: J1.B5 (CC2), R3.1
unnamed: J8.1, U1.24 (SWCLK)
unnamed: J8.3, U1.25 (SWD)
unnamed: J9.1, S1.3
unnamed: JP1.1 (A), R17.2
unnamed: JP2.1 (A), R15.2
unnamed: R6.1, SW2.1, SW2.4
unnamed: C1.2, U1.20 (XIN), Y1.3
unnamed: R16.2, U1.21 (XOUT)
QSPI_SCLK: U1.52 (QSPI_SCLK), U5.6 (CLK)
QSPI_SD0: U1.53 (QSPI_SD0), U5.5 (DI(IO0))
QSPI_SD2: U1.54 (QSPI_SD2), U5.3 (IO2)
QSPI_SD3: U1.51 (QSPI_SD3), U5.7 (IO3)
QSPI_SS: R6.2, R7.2, U1.56 (QSPI_SS), U5.1 (~CS)
QSPI_SSD1: U1.55 (QSPI_SD1), U5.2 (DO(IO1))
RX: SW3.1 (A), SW3.6 (C), U1.3 (GPIO1)
TX: SW3.3 (C), SW3.4 (A), U1.2 (GPIO0)
USB_DN: R4.2, U1.46 (USB_DM)
USB_DP: R5.2, U1.47 (USB_DP)
VBUS: F1.2, U2.3 (VI), U4.3 (VI)
VIN: C16.1, F1.1, S1.2; also elsewhere on the board

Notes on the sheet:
NEOPIXEL
RP2040 MCU
SPARKFUN QWIIC
STABILITY CAPS
RESET SW
DEBUG
STORAGE WINBOND CHIP
QWIIC PULL-UP
BLINKEN LIGHTS
USB-C & POWER

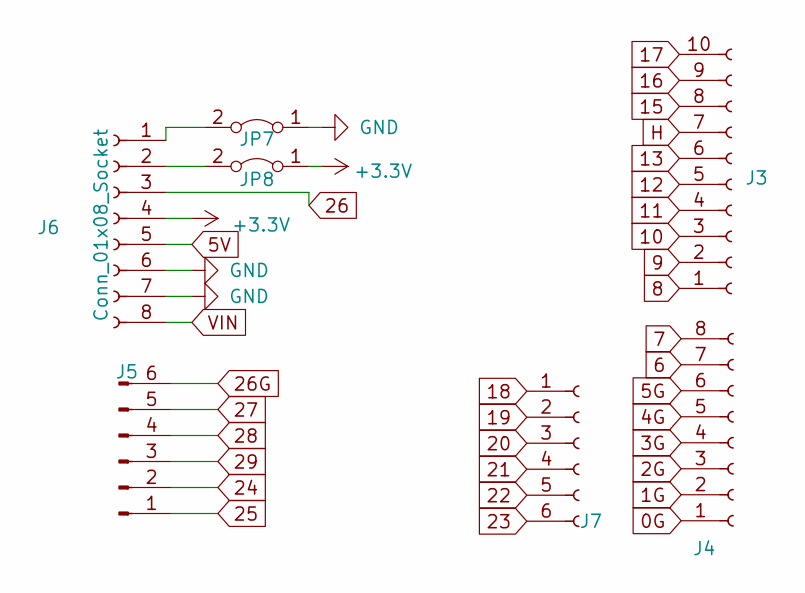
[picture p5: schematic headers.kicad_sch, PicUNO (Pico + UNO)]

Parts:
J3: Conn_01x10_Socket; PinSocket_1x10_P2.54mm_Vertical
J4, J6: Conn_01x08_Socket; PinSocket_1x08_P2.54mm_Vertical
J5: Conn_01x06_Pin; PinSocket_1x06_P2.54mm_Vertical
J7: Conn_01x06_Socket; PinSocket_1x06_P2.54mm_Vertical
JP7, JP8: Jumper_2_Bridged; SolderJumper-2_P1.3mm_Open_RoundedPad1.0x1.5mm

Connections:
3V: J6.4, JP8.1 (A); also elsewhere on the board
5V: J6.5; also elsewhere on the board
17: J3.10; also elsewhere on the board
20: J7.3; also elsewhere on the board
21: J7.4; also elsewhere on the board
24: J5.2; also elsewhere on the board
25: J5.1; also elsewhere on the board
26: J6.3; also elsewhere on the board
unnamed 67: J6.1, JP7.2 (B); also elsewhere on the board
unnamed 68: J6.2, JP8.2 (B); also elsewhere on the board
VIN: J6.8; also elsewhere on the board

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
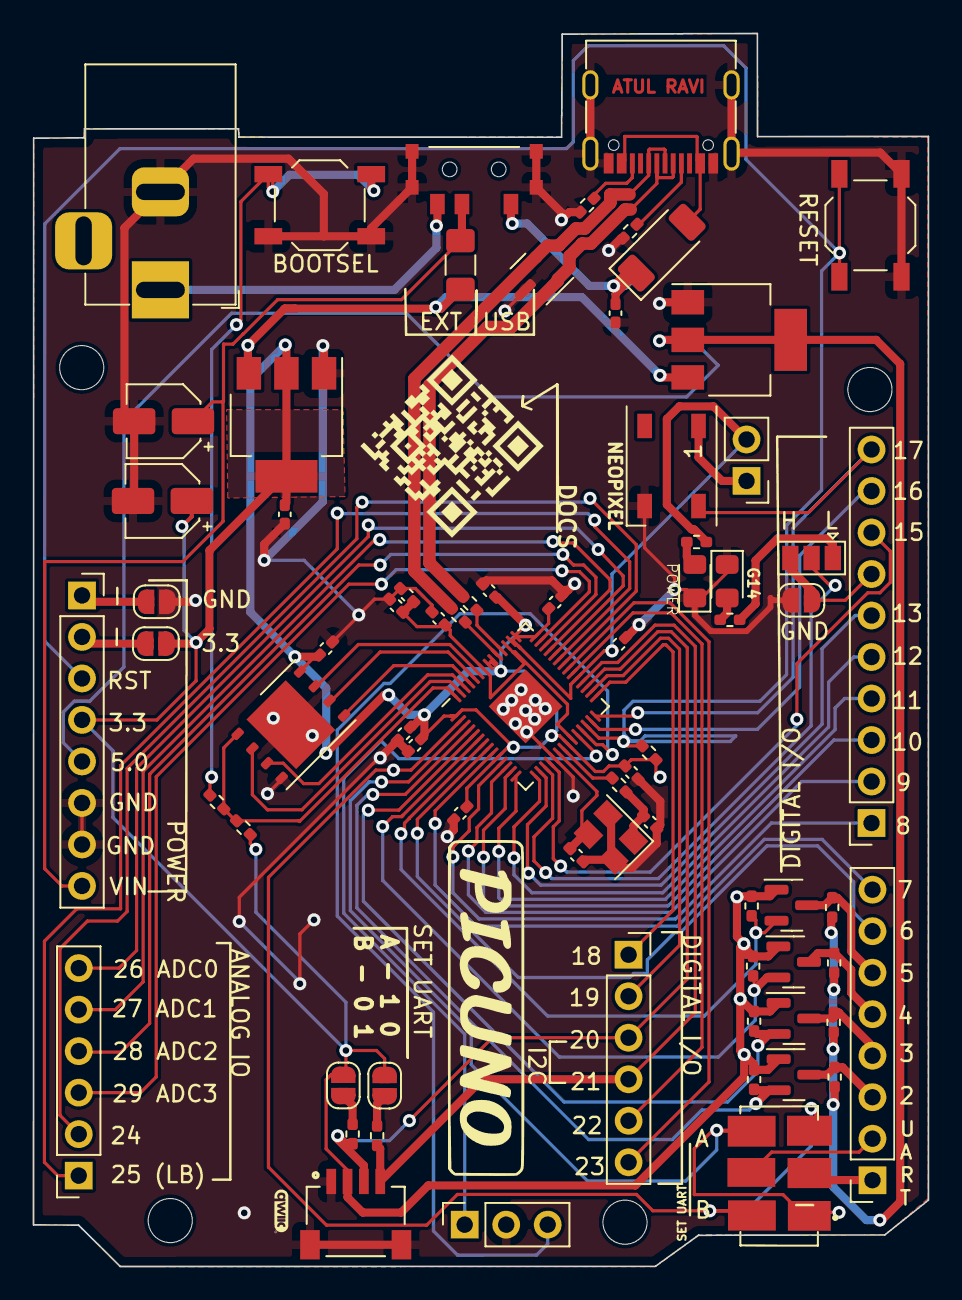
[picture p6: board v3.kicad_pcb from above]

Board: 2 copper layers, 54.8 x 75.5 mm, 75 parts (0 on the bottom side), 54 nets.

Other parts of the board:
D3: D_TVS_Dual_AAC; SOT-23
JP5, JP6: Jumper_2_Bridged; SolderJumper-2_P1.3mm_Open_RoundedPad1.0x1.5mm
REF1**, REF2**, REF3**: MountingHole_2.7mm_M2.5_ISO14580

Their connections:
3V: JP5.1 (A); also elsewhere on the board
unnamed 67: JP6.2 (B); also elsewhere on the board
unnamed 68: JP5.2 (B); also elsewhere on the board

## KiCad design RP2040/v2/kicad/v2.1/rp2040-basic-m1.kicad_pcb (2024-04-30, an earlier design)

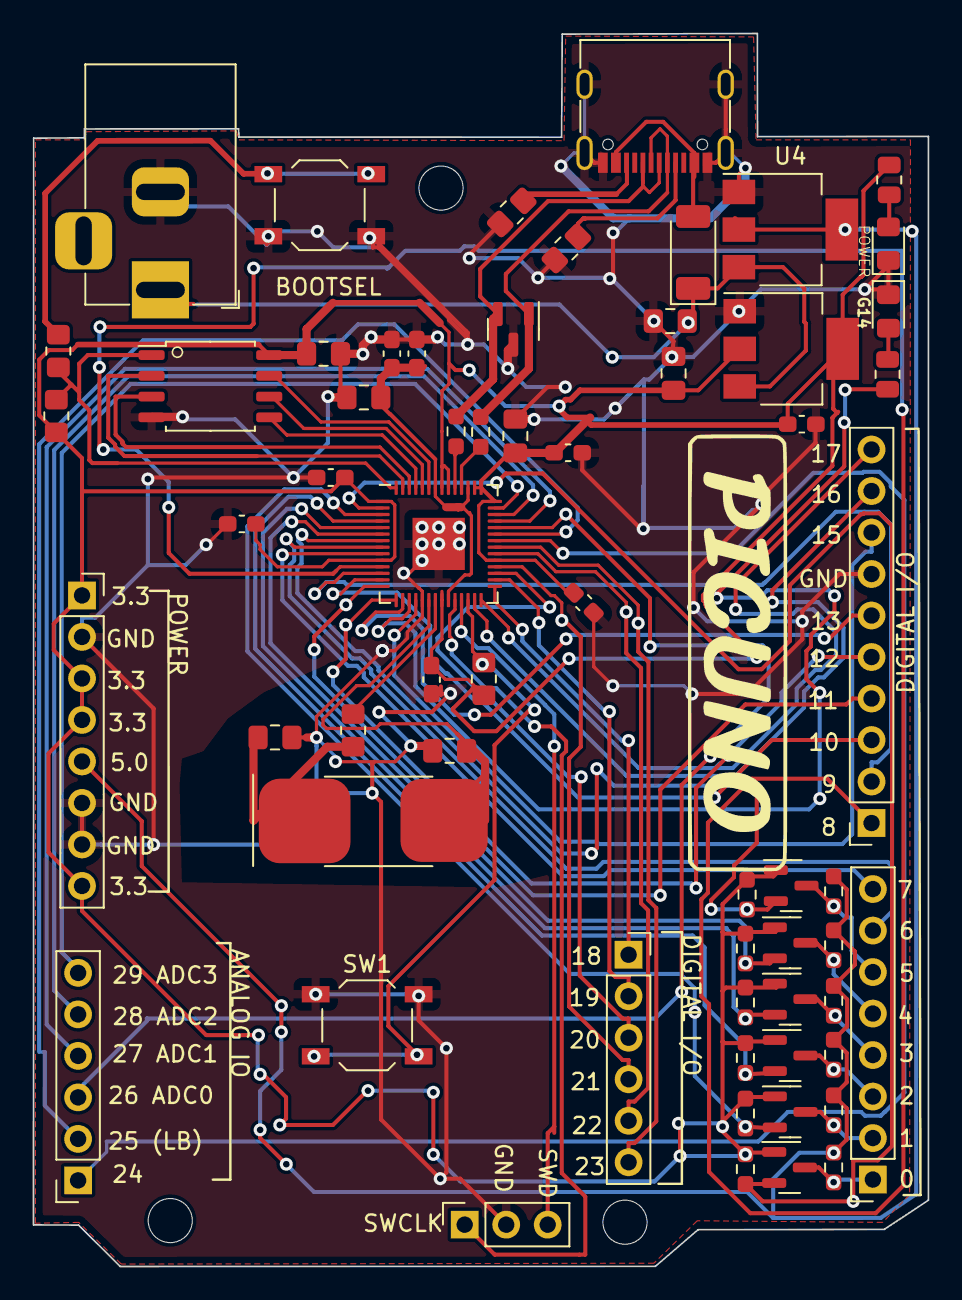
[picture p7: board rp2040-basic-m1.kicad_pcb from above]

Board: 2 copper layers, 54.8 x 75.5 mm, 62 parts (0 on the bottom side), 63 nets.

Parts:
C1, C2: 27p; C_0805_2012Metric_Pad1.18x1.45mm_HandSolder
C3, C4, C6, C7, C8, C9, C10, C11: 100n; C_0603_1608Metric_Pad1.08x0.95mm_HandSolder
C5, C12: 1u; C_0805_2012Metric_Pad1.18x1.45mm_HandSolder
C13, C14: 10u; C_0805_2012Metric_Pad1.18x1.45mm_HandSolder
C15: 100n; C_0805_2012Metric_Pad1.18x1.45mm_HandSolder
D1: D_Schottky; D_SOD-128
D3: D_TVS_Dual_AAC; SOT-23
D4, D5: LED; LED_0805_2012Metric_Pad1.15x1.40mm_HandSolder
J1: USB_C_Receptacle_USB2.0; USB_C_Receptacle_G-Switch_GT-USB-7010ASV
J3: Conn_01x10_Socket; PinSocket_1x10_P2.54mm_Vertical
J4, J6: Conn_01x08_Socket; PinSocket_1x08_P2.54mm_Vertical
J5: Conn_01x06_Pin; PinSocket_1x06_P2.54mm_Vertical
J7: Conn_01x06_Socket; PinSocket_1x06_P2.54mm_Vertical
J8: Conn_01x03_Pin; PinSocket_1x03_P2.54mm_Vertical
J9: Barrel_Jack_Switch; BarrelJack_Horizontal
Q1, Q2, Q3, Q4, Q5, Q6: BSS138; SOT-23
R1, R8: R_Small; R_0805_2012Metric
R2, R3, R33: 5.1K; R_0805_2012Metric_Pad1.20x1.40mm_HandSolder
R4, R5: 27R; R_0603_1608Metric_Pad0.98x0.95mm_HandSolder
R6, R16: 1k; R_0805_2012Metric_Pad1.20x1.40mm_HandSolder
R7: 10k; R_0805_2012Metric_Pad1.20x1.40mm_HandSolder
R9, R10, R11, R12, R13, R14, R18, R19, R20, R21, R22, R23: 10K; R_0603_1608Metric_Pad0.98x0.95mm_HandSolder
SW1, SW2: TACT SW; SW_SPST_TL3342
U1: RP2040; QFN-56-1EP_7x7mm_P0.4mm_EP3.2x3.2mm
U2: AZ1117CH-3.3TRG1 SOT223-3; SOT-223-3_TabPin2
U3: W25Q128JVS; SOIC-8_5.23x5.23mm_P1.27mm
U4: AMS1117-5.0; SOT-223-3_TabPin2
Y1: Crystal 12 Mhz; Crystal_SMD_SeikoEpson_MA505-2Pin_12.7x5.1mm_HandSoldering

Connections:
3V: C6.1, C7.1, C8.1, C9.1, C10.1, C11.1, C12.1, C14.1, C15.1, J6.1, J6.3, J6.4, J6.8, Q1.1 (G), Q2.1 (G), Q3.1 (G), Q4.1 (G), Q5.1 (G), Q6.1 (G), R1.1, R7.1, R9.2, R10.2, R11.2, R12.2, R13.2, R14.2, R33.1, U1.1 (IOVDD), U1.10 (IOVDD), U1.22 (IOVDD), U1.33 (IOVDD), U1.42 (IOVDD), U1.43 (ADC_AVDD), U1.44 (VREG_IN), U1.48 (USB_VDD), U1.49 (IOVDD), U2.2 (VO), U3.8 (VCC)
5V: J6.5, R18.2, R19.2, R20.2, R21.2, R22.2, R23.2, U4.2 (VO)
14: R8.2, U1.17 (GPIO14)
26: R33.2, SW1.2, U1.26 (RUN)
+1V1: C3.1, C4.1, C5.1, U1.23 (DVDD), U1.45 (VREG_VOUT), U1.50 (DVDD)
/USB1_DN: D3.1 (A1), J1.A7 (D-), J1.B7 (D-), R4.1
/USB1_DP: D3.2 (A2), J1.A6 (D+), J1.B6 (D+), R5.1
GND: C1.1, C2.1, C3.2, C4.2, C5.2, C6.2, C7.2, C8.2, C9.2, C10.2, C11.2, C12.2, C13.2, C14.2, C15.2, D3.3 (common), D4.1 (K), D5.1 (K), J1.A1 (GND), J1.A12 (GND), J1.B1 (GND), J1.B12 (GND), J1.S1 (SHIELD), J3.7, J6.2, J6.6, J6.7, J8.2, J9.2, R2.2, R3.2, SW1.1, SW2.2, U1.19 (TESTEN), U1.57 (GND), U2.1 (GND), U3.4 (GND), U4.1 (GND)
unnamed: C2.2, R16.1, Y1.1
unnamed: D1.2 (A), J1.A4 (VBUS), J1.A9 (VBUS), J1.B4 (VBUS), J1.B9 (VBUS)
unnamed: D4.2 (A), R8.1
unnamed: D5.2 (A), R1.2
unnamed: J1.A5 (CC1), R2.1
unnamed: J1.B5 (CC2), R3.1
unnamed: J3.1, U1.11 (GPIO8)
unnamed: J3.2, U1.12 (GPIO9)
unnamed: J3.3, U1.13 (GPIO10)
unnamed: J3.4, U1.14 (GPIO11)
unnamed: J3.5, U1.15 (GPIO12)
unnamed: J3.6, U1.16 (GPIO13)
unnamed: J3.8, U1.18 (GPIO15)
unnamed: J3.9, U1.27 (GPIO16)
unnamed: J3.10, U1.28 (GPIO17)
unnamed: J4.1, Q1.3 (D), R18.1
unnamed: J4.2, Q2.3 (D), R19.1
unnamed: J4.3, Q3.3 (D), R20.1
unnamed: J4.4, Q4.3 (D), R21.1
unnamed: J4.5, Q5.3 (D), R22.1
unnamed: J4.6, Q6.3 (D), R23.1
unnamed: J4.7, U1.8 (GPIO6)
unnamed: J4.8, U1.9 (GPIO7)
unnamed: J5.1, U1.36 (GPIO24)
unnamed: J5.2, U1.37 (GPIO25)
unnamed: J5.3, U1.38 (GPIO26_ADC0)
unnamed: J5.4, U1.39 (GPIO27_ADC1)
unnamed: J5.5, U1.40 (GPIO28_ADC2)
unnamed: J5.6, U1.41 (GPIO29_ADC3)
unnamed: J7.1, U1.29 (GPIO18)
unnamed: J7.2, U1.30 (GPIO19)
unnamed: J7.3, U1.31 (GPIO20)
unnamed: J7.4, U1.32 (GPIO21)
unnamed: J7.5, U1.34 (GPIO22)
unnamed: J7.6, U1.35 (GPIO23)
unnamed: J8.1, U1.24 (SWCLK)
unnamed: J8.3, U1.25 (SWD)
unnamed: Q1.2 (S), R9.1, U1.2 (GPIO0)
unnamed: Q2.2 (S), R10.1, U1.3 (GPIO1)
unnamed: Q3.2 (S), R11.1, U1.4 (GPIO2)
unnamed: Q4.2 (S), R12.1, U1.5 (GPIO3)
unnamed: Q5.2 (S), R13.1, U1.6 (GPIO4)
unnamed: Q6.2 (S), R14.1, U1.7 (GPIO5)
unnamed: R6.1, SW2.1
unnamed: C1.2, U1.20 (XIN), Y1.2
unnamed: R16.2, U1.21 (XOUT)
QSPI_SCLK: U1.52 (QSPI_SCLK), U3.6 (CLK)
QSPI_SD0: U1.53 (QSPI_SD0), U3.5 (DI(IO0))
QSPI_SD2: U1.54 (QSPI_SD2), U3.3 (IO2)
QSPI_SD3: U1.51 (QSPI_SD3), U3.7 (IO3)
QSPI_SS: R6.2, R7.2, U1.56 (QSPI_SS), U3.1 (~CS)
QSPI_SSD1: U1.55 (QSPI_SD1), U3.2 (DO(IO1))
USB_DN: R4.2, U1.46 (USB_DM)
USB_DP: R5.2, U1.47 (USB_DP)
VBUS: C13.1, D1.1 (K), J9.1, U2.3 (VI), U4.3 (VI)

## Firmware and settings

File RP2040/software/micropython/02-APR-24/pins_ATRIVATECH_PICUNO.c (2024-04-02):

// This file was automatically generated by make-pins.py
//
// --af-csv /home/atul/micropython/ports/rp2/boards/rp2_af.csv
// --board-csv /home/atul/micropython/ports/rp2/boards/ATRIVATECH_PICUNO/pins.csv
// --prefix /home/atul/micropython/ports/rp2/boards/rp2_prefix.c

#include <stdint.h>
#include "py/obj.h"
#include "py/mphal.h"
#include "extmod/modmachine.h"
#include "machine_pin.h"

#define AF(af_idx, af_fn, af_unit)                      \
    {                                                   \
        .base = { &machine_pin_af_type },               \
        .name = MP_QSTR_##af_fn,                        \
        .idx = (af_idx),                                \
        .fn = GPIO_FUNC_##af_fn,                        \
        .unit = (af_unit),                              \
    }

#if MICROPY_HW_PIN_EXT_COUNT
#define PIN(_id, _name, _is_ext, _af_num, _af_list)     \
    {                                                   \
        .base = { &machine_pin_type },                  \
        .name = MP_QSTR_##_name,                        \
        .id = (uint8_t)(_id),                           \
        .is_ext = (_is_ext),                            \
        .is_output = false,                             \
        .last_output_value = 0,                         \
        .af_num = (_af_num),                            \
        .af = (_af_list),                               \
    }
#else
#define PIN(_id, _name, _is_ext, _af_num, _af_list)     \
    {                                                   \
        .base = { &machine_pin_type },                  \
        .name = MP_QSTR_##_name,                        \
        .id = (uint8_t)(_id),                           \
        .af_num = (_af_num),                            \
        .af = (_af_list),                               \
    }
#endif
const machine_pin_af_obj_t pin_GPIO0_af[] = {
    AF(1, SPI , 0), // SPI0_RX
    AF(2, UART, 0), // UART0_TX
    AF(3, I2C , 0), // I2C0_SDA
    AF(4, PWM , 0), // PWM0_A
    AF(5, SIO , 0), // SIO
    AF(6, PIO0, 0), // PIO0
    AF(7, PIO1, 1), // PIO1
    AF(9, USB , 0), // USB_OVCUR_DET
};

const machine_pin_af_obj_t pin_GPIO1_af[] = {
    AF(1, SPI , 0), // SPI0_CS
    AF(2, UART, 0), // UART0_RX
    AF(3, I2C , 0), // I2C0_SCL
    AF(4, PWM , 0), // PWM0_B
    AF(5, SIO , 0), // SIO
    AF(6, PIO0, 0), // PIO0
    AF(7, PIO1, 1), // PIO1
    AF(9, USB , 0), // USB_VBUS_DET
};

const machine_pin_af_obj_t pin_GPIO2_af[] = {
    AF(1, SPI , 0), // SPI0_SCK
    AF(2, UART, 0), // UART0_CTS
    AF(3, I2C , 1), // I2C1_SDA
    AF(4, PWM , 1), // PWM1_A
    AF(5, SIO , 0), // SIO
    AF(6, PIO0, 0), // PIO0
    AF(7, PIO1, 1), // PIO1
    AF(9, USB , 0), // USB_VBUS_EN
};

const machine_pin_af_obj_t pin_GPIO3_af[] = {
    AF(1, SPI , 0), // SPI0_TX
    AF(2, UART, 0), // UART0_RTS
    AF(3, I2C , 1), // I2C1_SCL
    AF(4, PWM , 1), // PWM1_B
    AF(5, SIO , 0), // SIO
    AF(6, PIO0, 0), // PIO0
    AF(7, PIO1, 1), // PIO1
    AF(9, USB , 0), // USB_OVCUR_DET
};

const machine_pin_af_obj_t pin_GPIO4_af[] = {
    AF(1, SPI , 0), // SPI0_RX
    AF(2, UART, 1), // UART1_TX
    AF(3, I2C , 0), // I2C0_SDA
    AF(4, PWM , 2), // PWM2_A
    AF(5, SIO , 0), // SIO
    AF(6, PIO0, 0), // PIO0
    AF(7, PIO1, 1), // PIO1
    AF(9, USB , 0), // USB_VBUS_DET
};

const machine_pin_af_obj_t pin_GPIO5_af[] = {
    AF(1, SPI , 0), // SPI0_CS
    AF(2, UART, 1), // UART1_RX
    AF(3, I2C , 0), // I2C0_SCL
    AF(4, PWM , 2), // PWM2_B
    AF(5, SIO , 0), // SIO
    AF(6, PIO0, 0), // PIO0
    AF(7, PIO1, 1), // PIO1
    AF(9, USB , 0), // USB_VBUS_EN
};

const machine_pin_af_obj_t pin_GPIO6_af[] = {
    AF(1, SPI , 0), // SPI0_SCK
    AF(2, UART, 1), // UART1_CTS
    AF(3, I2C , 1), // I2C1_SDA
    AF(4, PWM , 3), // PWM3_A
    AF(5, SIO , 0), // SIO
    AF(6, PIO0, 0), // PIO0
    AF(7, PIO1, 1), // PIO1
    AF(9, USB , 0), // USB_OVCUR_DET
};

const machine_pin_af_obj_t pin_GPIO7_af[] = {
    AF(1, SPI , 0), // SPI0_TX
    AF(2, UART, 1), // UART1_RTS
    AF(3, I2C , 1), // I2C1_SCL
    AF(4, PWM , 3), // PWM3_B
    AF(5, SIO , 0), // SIO
    AF(6, PIO0, 0), // PIO0
    AF(7, PIO1, 1), // PIO1
    AF(9, USB , 0), // USB_VBUS_DET
};

const machine_pin_af_obj_t pin_GPIO8_af[] = {
    AF(1, SPI , 1), // SPI1_RX
    AF(2, UART, 1), // UART1_TX
    AF(3, I2C , 0), // I2C0_SDA
    AF(4, PWM , 4), // PWM4_A
    AF(5, SIO , 0), // SIO
    AF(6, PIO0, 0), // PIO0
    AF(7, PIO1, 1), // PIO1
    AF(9, USB , 0), // USB_VBUS_EN
};

const machine_pin_af_obj_t pin_GPIO9_af[] = {
    AF(1, SPI , 1), // SPI1_CS
    AF(2, UART, 1), // UART1_RX
    AF(3, I2C , 0), // I2C0_SCL
    AF(4, PWM , 4), // PWM4_B
    AF(5, SIO , 0), // SIO
    AF(6, PIO0, 0), // PIO0
    AF(7, PIO1, 1), // PIO1
    AF(9, USB , 0), // USB_OVCUR_DET
};

const machine_pin_af_obj_t pin_GPIO10_af[] = {
    AF(1, SPI , 1), // SPI1_SCK
    AF(2, UART, 1), // UART1_CTS
    AF(3, I2C , 1), // I2C1_SDA
    AF(4, PWM , 5), // PWM5_A
    AF(5, SIO , 0), // SIO
    AF(6, PIO0, 0), // PIO0
    AF(7, PIO1, 1), // PIO1
    AF(9, USB , 0), // USB_VBUS_DET
};

const machine_pin_af_obj_t pin_GPIO11_af[] = {
    AF(1, SPI , 1), // SPI1_TX
    AF(2, UART, 1), // UART1_RTS
    AF(3, I2C , 1), // I2C1_SCL
    AF(4, PWM , 5), // PWM5_B
    AF(5, SIO , 0), // SIO
    AF(6, PIO0, 0), // PIO0
    AF(7, PIO1, 1), // PIO1
    AF(9, USB , 0), // USB_VBUS_EN
};

const machine_pin_af_obj_t pin_GPIO12_af[] = {
    AF(1, SPI , 1), // SPI1_RX
    AF(2, UART, 0), // UART0_TX
    AF(3, I2C , 0), // I2C0_SDA
    AF(4, PWM , 6), // PWM6_A
    AF(5, SIO , 0), // SIO
    AF(6, PIO0, 0), // PIO0
    AF(7, PIO1, 1), // PIO1
    AF(9, USB , 0), // USB_OVCUR_DET
};

const machine_pin_af_obj_t pin_GPIO13_af[] = {
    AF(1, SPI , 1), // SPI1_CS
    AF(2, UART, 0), // UART0_RX
    AF(3, I2C , 0), // I2C0_SCL
    AF(4, PWM , 6), // PWM6_B
    AF(5, SIO , 0), // SIO
    AF(6, PIO0, 0), // PIO0
    AF(7, PIO1, 1), // PIO1
    AF(9, USB , 0), // USB_VBUS_DET
};

const machine_pin_af_obj_t pin_GPIO14_af[] = {
    AF(1, SPI , 1), // SPI1_SCK
    AF(2, UART, 0), // UART0_CTS
    AF(3, I2C , 1), // I2C1_SDA
    AF(4, PWM , 7), // PWM7_A
    AF(5, SIO , 0), // SIO
    AF(6, PIO0, 0), // PIO0
    AF(7, PIO1, 1), // PIO1
    AF(9, USB , 0), // USB_VBUS_EN
};

const machine_pin_af_obj_t pin_GPIO15_af[] = {
    AF(1, SPI , 1), // SPI1_TX
    AF(2, UART, 0), // UART0_RTS
    AF(3, I2C , 1), // I2C1_SCL
    AF(4, PWM , 7), // PWM7_B
    AF(5, SIO , 0), // SIO
    AF(6, PIO0, 0), // PIO0
    AF(7, PIO1, 1), // PIO1
    AF(9, USB , 0), // USB_OVCUR_DET
};

const machine_pin_af_obj_t pin_GPIO16_af[] = {
    AF(1, SPI , 0), // SPI0_RX
    AF(2, UART, 0), // UART0_TX
    AF(3, I2C , 0), // I2C0_SDA
    AF(4, PWM , 0), // PWM0_A
    AF(5, SIO , 0), // SIO
    AF(6, PIO0, 0), // PIO0
    AF(7, PIO1, 1), // PIO1
    AF(9, USB , 0), // USB_VBUS_DET
};
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

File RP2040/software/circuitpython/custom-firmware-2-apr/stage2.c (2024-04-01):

#include "sdk/src/rp2040/hardware_structs/include/hardware/structs/ssi.h"
#include "sdk/src/rp2040/hardware_structs/include/hardware/structs/pads_qspi.h"
#include "sdk/src/rp2040/hardware_regs/include/hardware/regs/addressmap.h"
#include "sdk/src/rp2040/hardware_regs/include/hardware/regs/m0plus.h"

// "Mode bits" are 8 special bits sent immediately after
// the address bits in a "Read Data Fast Quad I/O" command sequence.
// On W25Q080, the four LSBs are don't care, and if MSBs == 0xa, the
// next read does not require the 0xeb instruction prefix.
#define MODE_CONTINUOUS_READ 0xa0

// Define interface width: single/dual/quad IO

#define FRAME_FORMAT SSI_CTRLR0_SPI_FRF_VALUE_QUAD
#define TRANSACTION_TYPE SSI_SPI_CTRLR0_TRANS_TYPE_VALUE_2C2A
// Note that the INST_L field is used to select what XIP data gets pushed into
// the TX FIFO:
//      INST_L_0_BITS   {ADDR[23:0],XIP_CMD[7:0]}       Load "mode bits" into XIP_CMD
//      Anything else   {XIP_CMD[7:0],ADDR[23:0]}       Load SPI command into XIP_CMD
#define INSTRUCTION_LENGTH SSI_SPI_CTRLR0_INST_L_VALUE_NONE
#define READ_INSTRUCTION MODE_CONTINUOUS_READ
#define ADDR_L 8 // 6 for address, 2 for mode


#define CMD_READ_STATUS1 0x05
#define CMD_READ_STATUS2 0x35
#define CMD_WRITE_ENABLE 0x06
#define CMD_WRITE_STATUS1 0x01
#define CMD_WRITE_STATUS2 0x31

#define SREG_DATA 0x02

static uint32_t wait_and_read(uint8_t);
static uint8_t read_flash_sreg(uint8_t status_command);

// This function is use by the bootloader to enable the XIP flash. It is also
// used by the SDK to reinit XIP after doing non-read flash interactions such as
// writing or erasing. This code must compile down to position independent
// assembly because we don't know where in RAM it'll be when run.

// This must be the first defined function so that it is placed at the start of
// memory where the bootloader jumps to!
extern void _stage2_boot(void);
void __attribute__((section(".entry._stage2_boot"), used)) _stage2_boot(void) {
    uint32_t lr;
    asm ("MOV %0, LR\n" : "=r" (lr) );

    // Set aggressive pad configuration for QSPI
    // - SCLK 8mA drive, no slew limiting
    // - SDx disable input Schmitt to reduce delay

    // SCLK
    pads_qspi_hw->io[0] = PADS_QSPI_GPIO_QSPI_SCLK_DRIVE_VALUE_8MA << PADS_QSPI_GPIO_QSPI_SCLK_DRIVE_LSB |
                          PADS_QSPI_GPIO_QSPI_SCLK_SLEWFAST_BITS;

    // Data lines
    uint32_t data_settings = pads_qspi_hw->io[1];
    data_settings &= ~PADS_QSPI_GPIO_QSPI_SCLK_SCHMITT_BITS;
    pads_qspi_hw->io[2] = data_settings;
    
    pads_qspi_hw->io[1] = data_settings;
    pads_qspi_hw->io[3] = data_settings;
    pads_qspi_hw->io[4] = data_settings;
    

    // Disable the SSI so we can change the settings.
    ssi_hw->ssienr = 0;

    // QSPI config
    ssi_hw->baudr = 4; // 125 mhz / clock divider

    // Set 1-cycle sample delay. If PICO_FLASH_SPI_CLKDIV == 2 then this means,
    // if the flash launches data on SCLK posedge, we capture it at the time that
    // the next SCLK posedge is launched. This is shortly before that posedge
    // arrives at the flash, so data hold time should be ok. For
    // PICO_FLASH_SPI_CLKDIV > 2 this pretty much has no effect.
    ssi_hw->rx_sample_dly = 1;

    // Set a temporary mode for doing simple commands.
    ssi_hw->ctrlr0 = (7 << SSI_CTRLR0_DFS_32_LSB) | // 8 bits per data frame
                     (SSI_CTRLR0_TMOD_VALUE_TX_AND_RX << SSI_CTRLR0_TMOD_LSB);

    ssi_hw->ssienr = 0x1;

    
    // Program status register.
    // Enable SSI and select slave 0
    
    uint8_t result = read_flash_sreg(CMD_READ_STATUS2);
    
    if (result != 2) {
        ssi_hw->dr0 = (uint8_t) CMD_WRITE_ENABLE;
        wait_and_read(1);

        
        ssi_hw->dr0 = (uint8_t) CMD_WRITE_STATUS1;
        
        ssi_hw->dr0 = 0x0;
        
        ssi_hw->dr0 = 2;
        wait_and_read(3);
        
        // Wait for the write to complete.
        while ((read_flash_sreg(CMD_READ_STATUS1) & 0x1) != 0) {}
    }
    

    // Disable SSI again so that it can be reconfigured
    ssi_hw->ssienr = 0;

    // Do a single read to get us in continuous mode.

    // Final SSI ctrlr0 settings. We only change the SPI specific settings later.
    ssi_hw->ctrlr0 = (FRAME_FORMAT << SSI_CTRLR0_SPI_FRF_LSB) | // Quad I/O mode
                     (31 << SSI_CTRLR0_DFS_32_LSB)  |       // 32 data bits
                     (SSI_CTRLR0_TMOD_VALUE_EEPROM_READ << SSI_CTRLR0_TMOD_LSB);    // Send INST/ADDR, Receive Data

    ssi_hw->ctrlr1 = 0; // Single 32b read

    
    ssi_hw->spi_ctrlr0 = (ADDR_L << SSI_SPI_CTRLR0_ADDR_L_LSB) | // Address + mode bits
                         // Hi-Z dummy clocks following address + mode
                         (4 << SSI_SPI_CTRLR0_WAIT_CYCLES_LSB) |
                         // 8-bit instruction
                         (SSI_SPI_CTRLR0_INST_L_VALUE_8B << SSI_SPI_CTRLR0_INST_L_LSB) |
                         // Send Command in serial mode then address in Quad I/O mode
                         (SSI_SPI_CTRLR0_TRANS_TYPE_VALUE_1C2A << SSI_SPI_CTRLR0_TRANS_TYPE_LSB);

    // Re-enable the SSI
    ssi_hw->ssienr = 1;

    // Do a single read to get us in continuous mode.
    ssi_hw->dr0 = 0xeb;
    ssi_hw->dr0 = MODE_CONTINUOUS_READ;
    wait_and_read(2);

    // Disable the SSI to switch to no-command mode (because we're setup for continuous.)
    ssi_hw->ssienr = 0;
    

    // Final SPI ctrlr0 settings.
    ssi_hw->spi_ctrlr0 = (READ_INSTRUCTION << SSI_SPI_CTRLR0_XIP_CMD_LSB) | // Mode bits to keep flash in continuous read mode
                         (ADDR_L << SSI_SPI_CTRLR0_ADDR_L_LSB) |    // Total number of address + mode bits
                         (4 << SSI_SPI_CTRLR0_WAIT_CYCLES_LSB) |    // Hi-Z dummy clocks following address + mode
                         (INSTRUCTION_LENGTH << SSI_SPI_CTRLR0_INST_L_LSB) | // Do not send a command, instead send XIP_CMD as mode bits after address
                         (TRANSACTION_TYPE << SSI_SPI_CTRLR0_TRANS_TYPE_LSB); // Send Address in Quad I/O mode (and Command but that is zero bits long)

    // Re-enable the SSI
    ssi_hw->ssienr = 1;

    // If lr is 0, then we came from the bootloader.
    if (lr == 0) {
        uint32_t* vector_table = (uint32_t*) (XIP_BASE + 0x100);
        // Switch the vector table to immediately after the stage 2 area.
        *((uint32_t *) (PPB_BASE + M0PLUS_VTOR_OFFSET)) = (uint32_t) vector_table;
        // Set the top of the stack according to the vector table.
        asm volatile ("MSR msp, %0" : : "r" (vector_table[0]) : );
        // The reset handler is the second entry in the vector table
        asm volatile ("bx %0" : : "r" (vector_table[1]) : );
        // Doesn't return. It jumps to the reset handler instead.
    }
    // Otherwise we return.
}
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

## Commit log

2024-01-22 Add files via upload
    Gerbers are of V1. Kicad files are of V2
    [rp2040-basic-m1 - Copy.kicad_pcb, rp2040-basic-m1.csv, rp2040-basic-m1.kicad_pcb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]
2024-01-23 Gerbers and RAR Files for fabrication UPLOADED
    All files incl gerbers and rar and zip added.
    [rp2040-basic-m1-B_Adhesive.gbr, rp2040-basic-m1-B_Courtyard.gbr, rp2040-basic-m1-B_Cu.gbr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]
2024-01-23 Schematic uploaded to directory via UPLOAD
    Schematic uploaded to directory
2024-01-23 Assembly files BOM etc added via UPLOAD
    Files uploaded
    [rp2040-basic-m1.csv, rp2040-basic-m1.xlsx]
2024-01-23 Kicad files added via UPLOAD
    [rp2040-basic-m1 - Copy.kicad_pcb, rp2040-basic-m1.kicad_pcb, rp2040-basic-m1.kicad_sch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]
2024-01-25 KiCad files added via UPLOAD for V2.1
    KiCad files added via UPLOAD for V2.1
    [flash.kicad_sch, rp2040-basic-m1 - Copy.kicad_pcb, rp2040-basic-m1.kicad_pcb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]
2024-01-28 V2.2 Final files added.
    Diffrential Routing errors fixed.
    [rp2040-basic-m1.kicad_pcb, rp2040-basic-m1.kicad_sch]
2024-01-28 GEBER files of V2.2 Added
    Possibly final iteration
    [rp2040-basic-m1-B_Adhesive.gbr, rp2040-basic-m1-B_Courtyard.gbr, rp2040-basic-m1-B_Cu.gbr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]
2024-01-28 Schematic PDF added via upload
2024-01-28 readme for schematics made
2024-01-29 V2.2.1 folder created for updated PCB
2024-01-29 Kicad FIles with changes mentioned in Readme of V2.2.1 Added
    [flash.kicad_sch, rp2040-basic-m1 - Copy.kicad_pcb, rp2040-basic-m1.kicad_pcb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]
2024-01-29 V2.2.1 Gerbers with changed in readme VIA UPLOAD
    V2.2.1 files with 2 less logic level shifters and India Flag under Winbond Flash added.
    [rp2040-basic-m1-B_Adhesive.gbr, rp2040-basic-m1-B_Courtyard.gbr, rp2040-basic-m1-B_Cu.gbr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]
2024-02-09 Create readme.md for 3.3V version
2024-02-09 Create readme.md Gerber files for 3.3
2024-02-09 Gerbers RAR added via upload
2024-02-09 Create readme.md for 3.3V picuno
2024-02-09 Gerber files and build files added via upload
    [rp2040-basic-m1-B_Adhesive.gbr, rp2040-basic-m1-B_Courtyard.gbr, rp2040-basic-m1-B_Cu.gbr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]
2024-02-14 PCB3D file added for blender
2024-02-15 Update README.md with kicad and product pic
2024-02-16 BOM and Fab costing calculation Excel files added.
    [BOM.csv, cost-calculations-manufacture-picuno.xlsx]
2024-02-17 Update README.md with current proto ver
2024-02-20 Create readme.md for 2.2.3 kicad
2024-02-20 kicad files for 2.2.3 added via upload
    [rp2040-basic-m1.kicad_pcb, rp2040-basic-m1.kicad_sch]
2024-02-20 Update and rename rp2040-basic-m1 - Copy.kicad_pcb to old/rp2040-basic-m1 - Copy.kicad_pcb
    [rp2040-basic-m1 - Copy.kicad_pcb]
2024-02-20 Update and rename rp2040-basic-m1.kicad_sch to old/rp2040-basic-m1.kicad_sch
    [rp2040-basic-m1.kicad_sch]
2024-02-20 Update and rename rp2040-basic-m1.kicad_pcb to old/rp2040-basic-m1.kicad_pcb
    [rp2040-basic-m1.kicad_pcb]
2024-02-20 Rename rp2040-basic-m1 - Copy.kicad_pro to old/rp2040-basic-m1 - Copy.kicad_pro
2024-02-20 Rename rp2040-basic-m1 - Copy.kicad_prl to old/rp2040-basic-m1 - Copy.kicad_prl
2024-03-21 Files added
    [BOM.csv, Quoatation-Lion-Circuits.xlsx, cost-calculations-manufacture-picuno.xlsx]
2024-03-24 Picuno 5V gerbers and Visual Place file uploaded.
    [rp2040-5v-pos.csv, rp2040-basic-m1-B_Adhesive.gbr, rp2040-basic-m1-B_Courtyard.gbr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]
2024-03-24 Gerber files of 5V 2.2.3 Edition for visualplace.
    [rp2040-basic-m1-B_Adhesive.gbr, rp2040-basic-m1-B_Courtyard.gbr, rp2040-basic-m1-B_Cu.gbr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]
2024-03-28 POS files added
    [rp2040-pos.csv]
2024-04-01 Circuit Python FIles added for testing
2024-04-20 Gerbers for V2.5 Added via upload
    [rp2040-basic-m1-B_Adhesive.gbr, rp2040-basic-m1-B_Courtyard.gbr, rp2040-basic-m1-B_Cu.gbr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]
2024-04-20 Kicad files for 2.5 added via upload
    [rp2040-basic-m1.kicad_pcb, rp2040-basic-m1.kicad_sch]
2024-04-30 Moved all files to RP2040 folder
    [BOM-2.csv, BOM.csv, Quoatation-Lion-Circuits.xlsx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]
